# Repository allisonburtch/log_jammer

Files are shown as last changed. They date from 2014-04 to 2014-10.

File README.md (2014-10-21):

Hi there. I found [this](http://www.electroschematics.com/wp-content/uploads/2009/01/cell-phone-jammer-schematic.gif) cell phone jammer on the internet. It is for the GSM 1900 spectrum. Many of these parts are legacy and I had to figure out replacements. If you look at the actual schematic in Eagle, I've noted the new name of each part. Feel free to email me with questions: allison//at//allisonburtch.net

Schematic in Eagle of triangle wave generator, voltage inverter and noise generator.
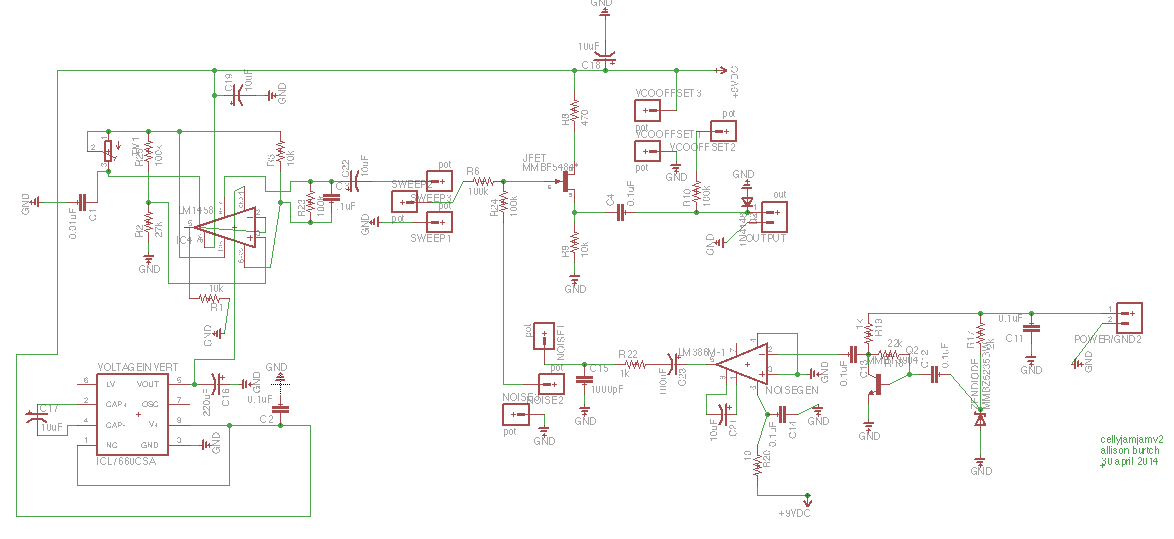
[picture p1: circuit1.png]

Schematic of the VCO and rf amplifier leading to antenna.
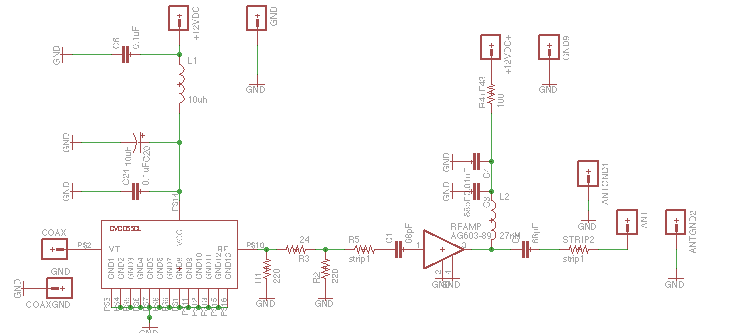
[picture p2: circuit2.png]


This is the board layout of the rf part in Eagle.
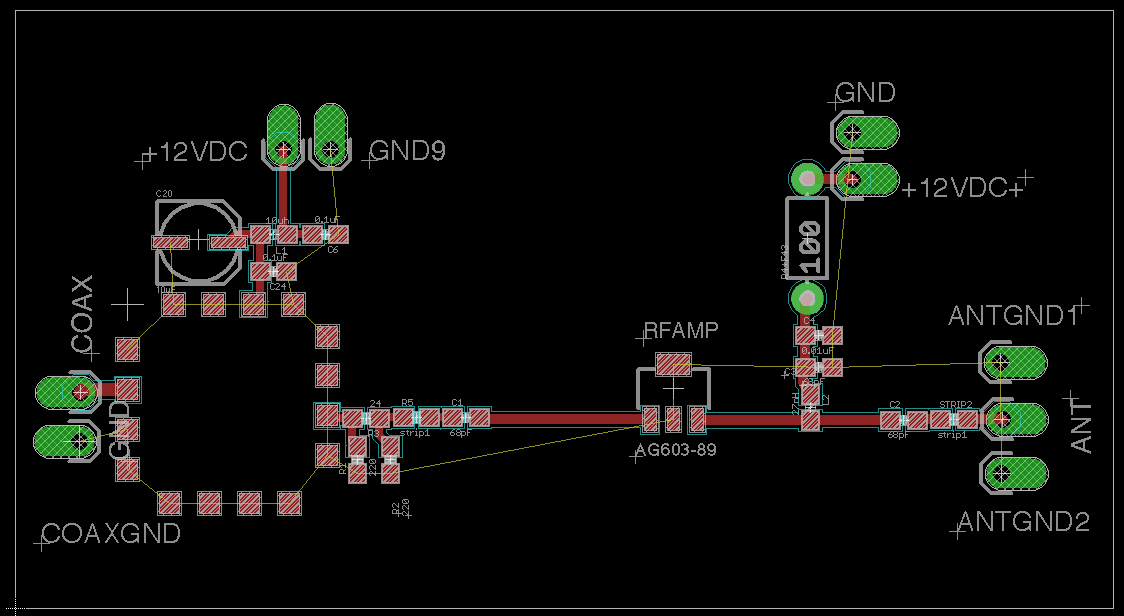
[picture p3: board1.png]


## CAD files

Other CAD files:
jammer_smdv3-tcream.dxf
rf_part/rfv1-tcream.dxf
vinyl_cut_rf_board/rfv1_multiple-tcream.dxf
cellyjamjam_v2-tcream.dxf
rf_part/rfv1-bcream.dxf
vinyl_cut_rf_board/rfv1_multiple-bcream.dxf
jammer_smdv3-bcream.dxf

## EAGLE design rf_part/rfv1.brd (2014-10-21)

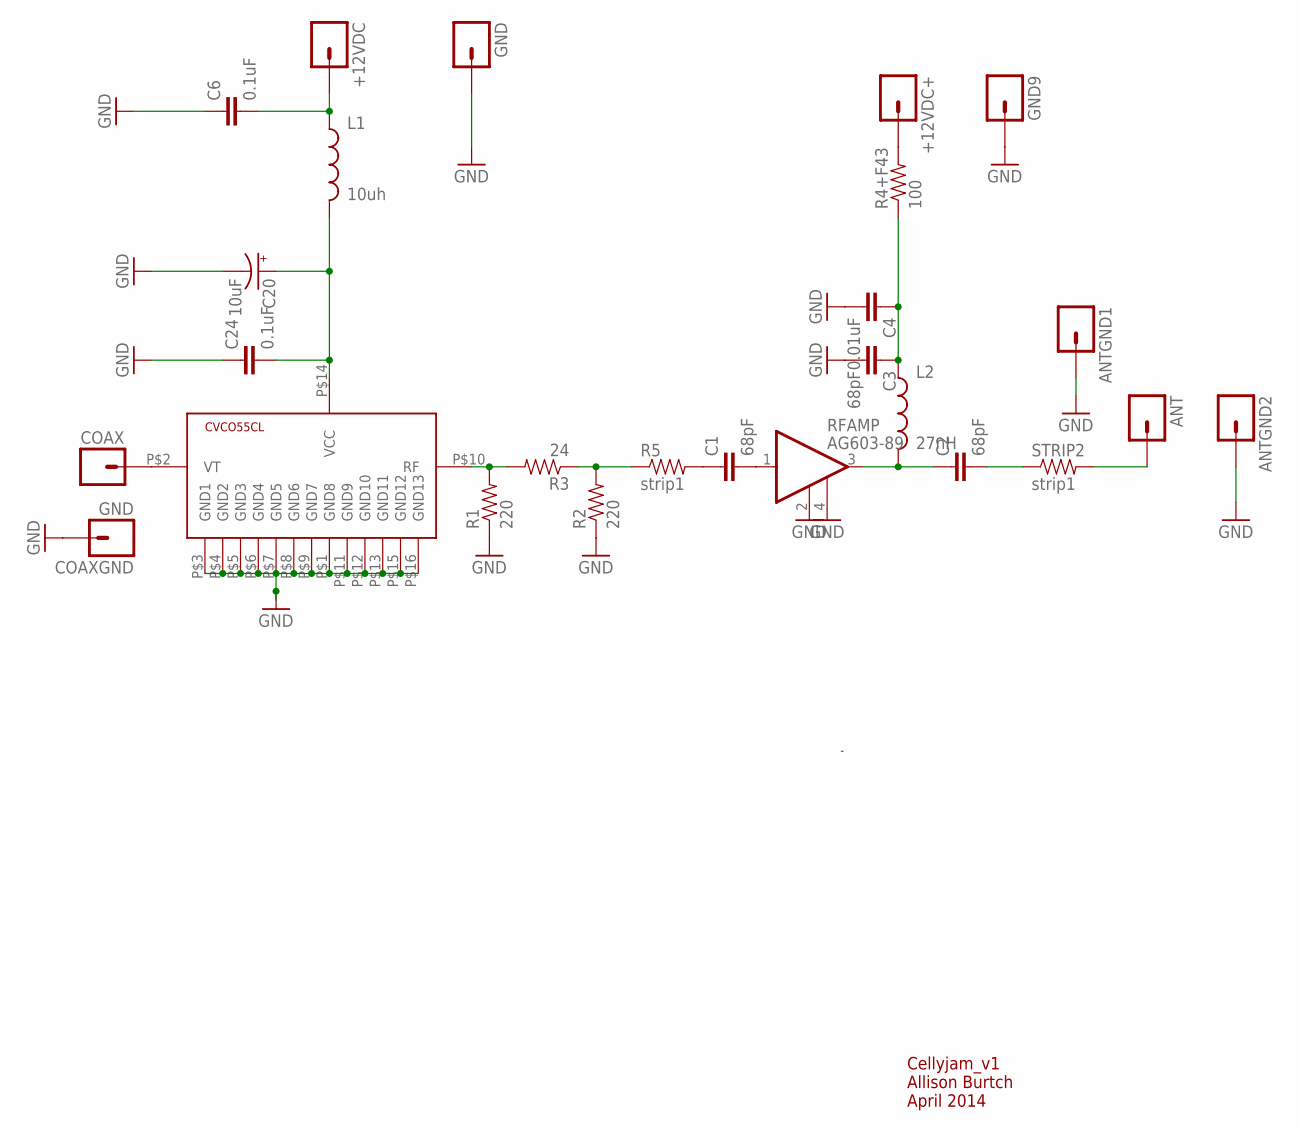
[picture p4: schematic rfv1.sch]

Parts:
+12VDC, +12VDC+: M01OFFSET; 1X01_OFFSET
ANT: M01OFFSET; 1X01_OFFSET
ANTGND1, ANTGND2: M01OFFSET; 1X01_OFFSET
C1, C2, C3: 68pF; 0603-CAP
C4: 0.01uF; 0603-CAP
C6, C24: 0.1uF; 0603-CAP
C20: 10uF; PANASONIC_C
COAX: M01OFFSET; 1X01_OFFSET
COAXGND: GND; 1X01_OFFSET
GND, GND9: M01OFFSET; 1X01_OFFSET
L1: 10uh; 0603
L2: 27nH; 0603
R1, R2: 220; 0603-RES
R3: 24; 0603-RES
R4+F43: 100; AXIAL-0.3-KIT
R5: strip1; 0603-RES
RFAMP: AG603-89; SOT89
STRIP2: strip1; 0603-RES
U$1: CVCO55CL

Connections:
GND: ANTGND1.1, ANTGND2.1, C3.2, C4.2, C6.1, C20.-, C24.1, COAXGND.1, GND.1, GND9.1, R1.1, R2.1, RFAMP.2 (GND), RFAMP.4 (GND), U$1.P$1 (GND8), U$1.P$3 (GND1), U$1.P$4 (GND2), U$1.P$5 (GND3), U$1.P$6 (GND4), U$1.P$7 (GND5), U$1.P$8 (GND6), U$1.P$9 (GND7), U$1.P$11 (GND9), U$1.P$12 (GND10), U$1.P$13 (GND11), U$1.P$15 (GND12), U$1.P$16 (GND13)
unnamed: COAX.1, U$1.P$2 (VT)
unnamed: R1.2, R3.2, U$1.P$10 (RF)
unnamed: R2.2, R3.1, R5.1
unnamed: C1.2, RFAMP.1 (IN)
unnamed: C2.1, L2.2, RFAMP.3 (OUT)
unnamed: C3.1, C4.1, L2.1, R4+F43.P$1 (1)
unnamed: +12VDC.1, C6.2, L1.1
unnamed: +12VDC+.1, R4+F43.P$2 (2)
unnamed: C2.2, STRIP2.1
unnamed: ANT.1, STRIP2.2
unnamed: C1.1, R5.2
unnamed: C20.+, C24.2, L1.2, U$1.P$14 (VCC)

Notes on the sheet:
Cellyjam_v1 Allison Burtch April 2014

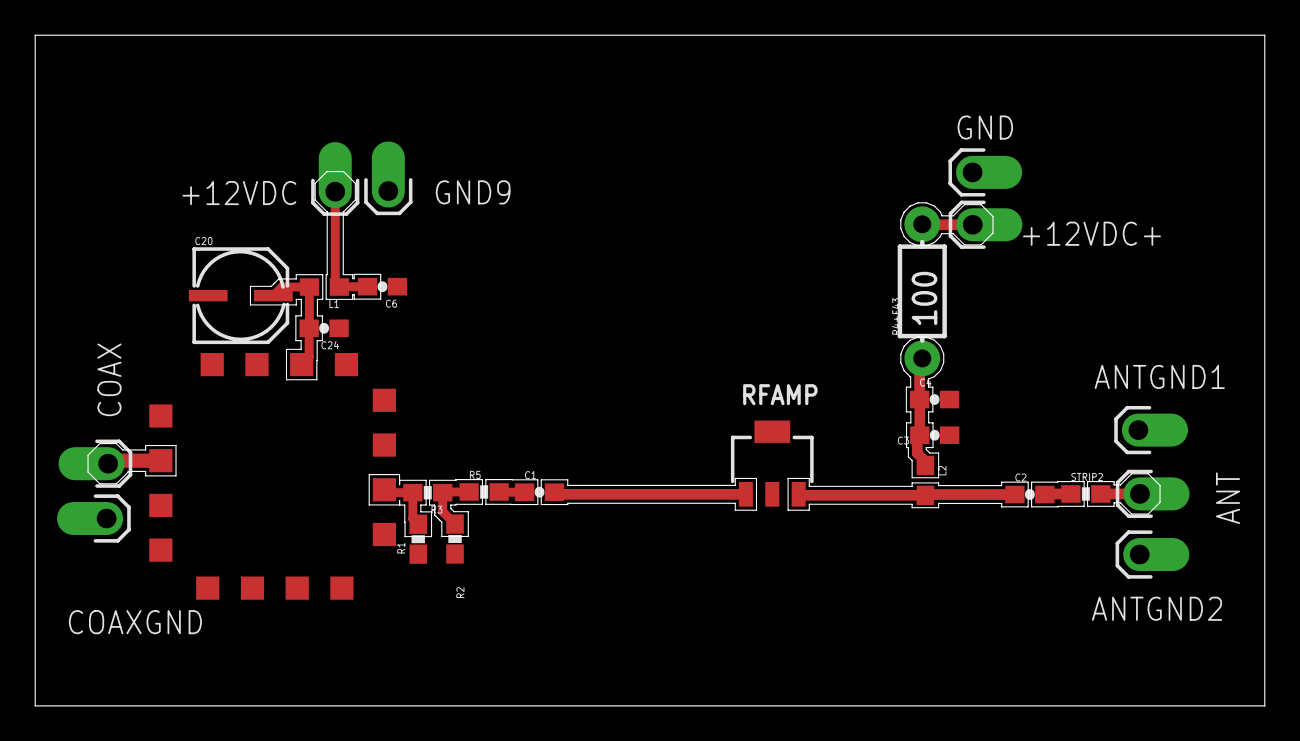
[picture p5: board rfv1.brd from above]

Board: 2 copper layers, 69.8 x 38.1 mm, 26 parts (0 on the bottom side), 13 nets.

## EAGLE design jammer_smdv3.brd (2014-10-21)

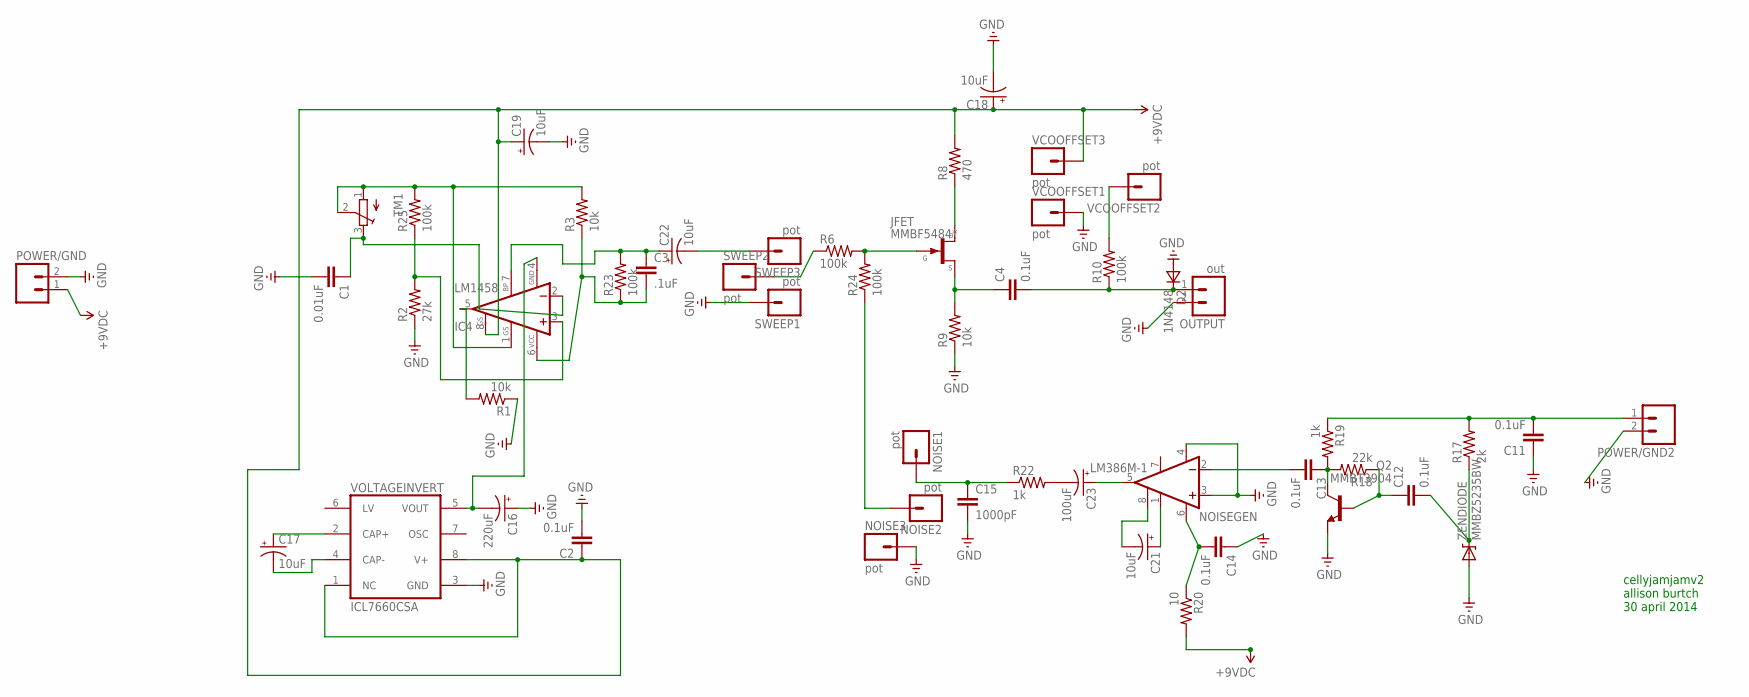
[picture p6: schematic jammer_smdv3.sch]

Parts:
C1: 0.01uF; 0603-CAP
C2, C4, C11, C12, C13, C14: 0.1uF; 0603-CAP
C3: .1uF; 0603-CAP
C15: 1000pF; 0603-CAP
C16: 220uF; PANASONIC_D
C17, C22: 10uF; PANASONIC_C
C18, C19, C21: 10uF; EIA3216
C23: 100uF; CPOL-RADIAL-100UF-25V
D2: 1N4148; SOD323
IC4: LM1458; SO08@2
JFET: MMBF5484*; SOT23
NOISE1, NOISE2, NOISE3: pot; 1X01
NOISEGEN: LM386M-1; SO08
OUTPUT: out; 1X02_LOCK_LONGPADS
POWER/GND, POWER/GND2: M02LOCK_LONGPADS; 1X02_LOCK_LONGPADS
Q2: MMBT3904; SOT23-BEC
R1, R3, R9: 10k; 0603-RES
R2: 27k; 0603-RES
R6, R10, R23, R24, R25: 100k; 0603-RES
R8: 470; 0603-RES
R17: 2k; 0603-RES
R18: 22k; 0603-RES
R19, R22: 1k; 0603-RES
R20: 10; 0603-RES
SWEEP1, SWEEP2, SWEEP3: pot; 1X01
TM1: TRIMPOTTC33X; TC33X
VCOOFFSET1, VCOOFFSET2, VCOOFFSET3: pot; 1X01
VOLTAGEINVERT: ICL7660CSA; SO08
ZENDIODE: MMBZ5235BW; DIODE-ZENER

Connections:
GND: C1.2, C2.2, C11.1, C14.1, C15.2, C16.+, C18.C (-), C19.C (-), D2.2 (A), NOISE3.1, NOISEGEN.3 (+IN), NOISEGEN.4 (GND), OUTPUT.2, POWER/GND.2, POWER/GND2.2, Q2.E, R1.1, R2.1, R9.1, SWEEP1.1, VCOOFFSET1.1, VOLTAGEINVERT.3 (GND), ZENDIODE.P$2 (A)
unnamed: C17.+, VOLTAGEINVERT.2 (CAP+)
unnamed: C17.-, VOLTAGEINVERT.4 (CAP-)
unnamed: C21.A (+), NOISEGEN.1 (GAIN)
unnamed: C16.-, IC4.4 (GND), VOLTAGEINVERT.5 (VOUT)
unnamed: IC4.1 (GAIN), R3.2, R25.2, TM1.1 (A), TM1.2 (S)
unnamed: C1.1, IC4.2 (-IN), TM1.3 (E)
unnamed: R6.1, SWEEP2.1
unnamed: C22.-, SWEEP3.1
unnamed: C3.2, IC4.6 (VS), R3.1, R23.1
unnamed: C21.C (-), NOISEGEN.8 (GAIN)
unnamed: C12.1, Q2.B, R18.1
unnamed: C13.2, NOISEGEN.2 (-IN)
unnamed: C13.1, Q2.C, R18.2, R19.2
unnamed: C12.2, R17.1, ZENDIODE.P$1 (C)
unnamed: C23.2 (-), R22.2
unnamed: C23.1 (+), NOISEGEN.5 (OUT)
unnamed: C15.1, NOISE1.1, R22.1
unnamed: C3.1, C22.+, IC4.7 (BS2), R23.2
unnamed: NOISE2.1, R24.1
unnamed: C14.2, NOISEGEN.6 (VS), R20.1
unnamed: JFET.1 (D), R8.1
unnamed: C4.1, JFET.2 (S), R9.2
unnamed: R10.2, VCOOFFSET2.1
unnamed: C11.2, POWER/GND2.1, R17.2, R19.1
unnamed: JFET.3 (G), R6.2, R24.2
unnamed: IC4.5 (OUT), R1.2
unnamed: IC4.3 (+IN), R2.2, R25.1
unnamed: C4.2, D2.1 (C), OUTPUT.1, R10.1
VCC: C2.1, C18.A (+), C19.A (+), IC4.8 (GAIN), POWER/GND.1, R8.2, R20.2, VCOOFFSET3.1, VOLTAGEINVERT.1 (NC), VOLTAGEINVERT.8 (V+)

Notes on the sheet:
cellyjamjamv2 allison burtch 30 april 2014

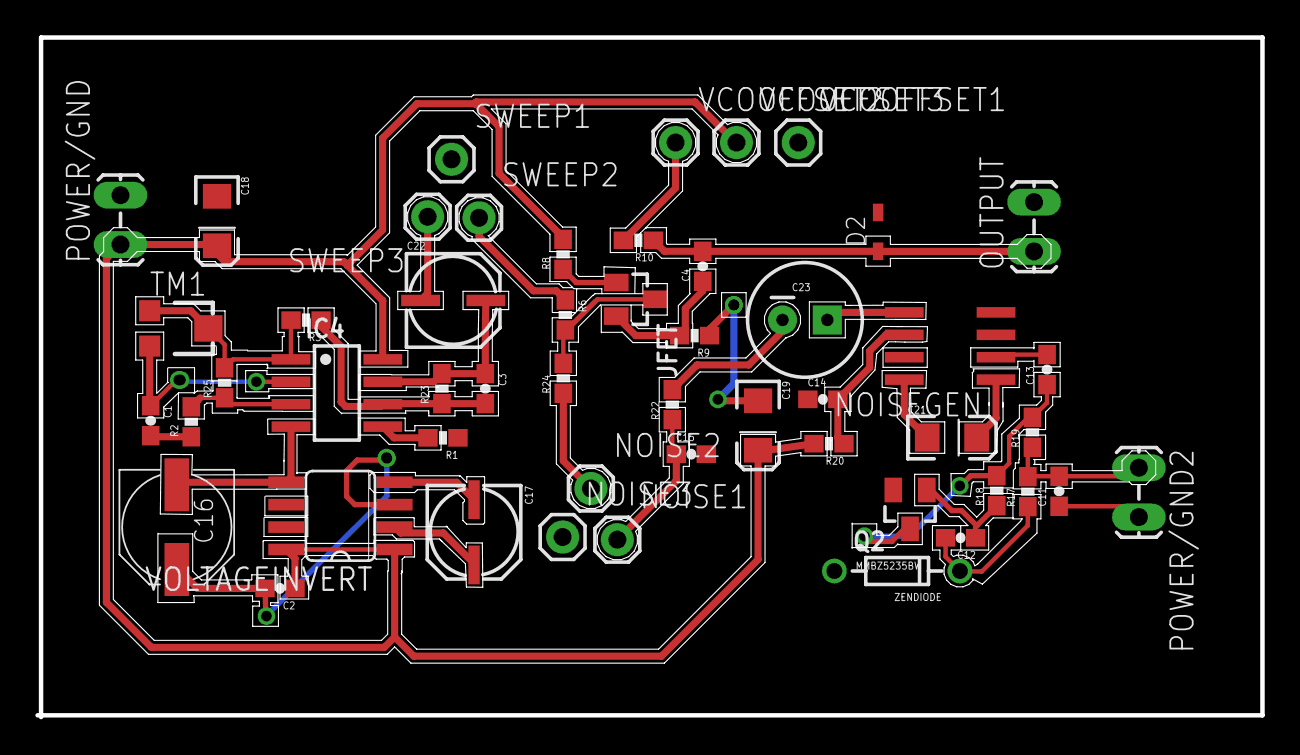
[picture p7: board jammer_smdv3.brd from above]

Board: 2 copper layers, 69.4 x 38.5 mm, 51 parts (0 on the bottom side), 30 nets.

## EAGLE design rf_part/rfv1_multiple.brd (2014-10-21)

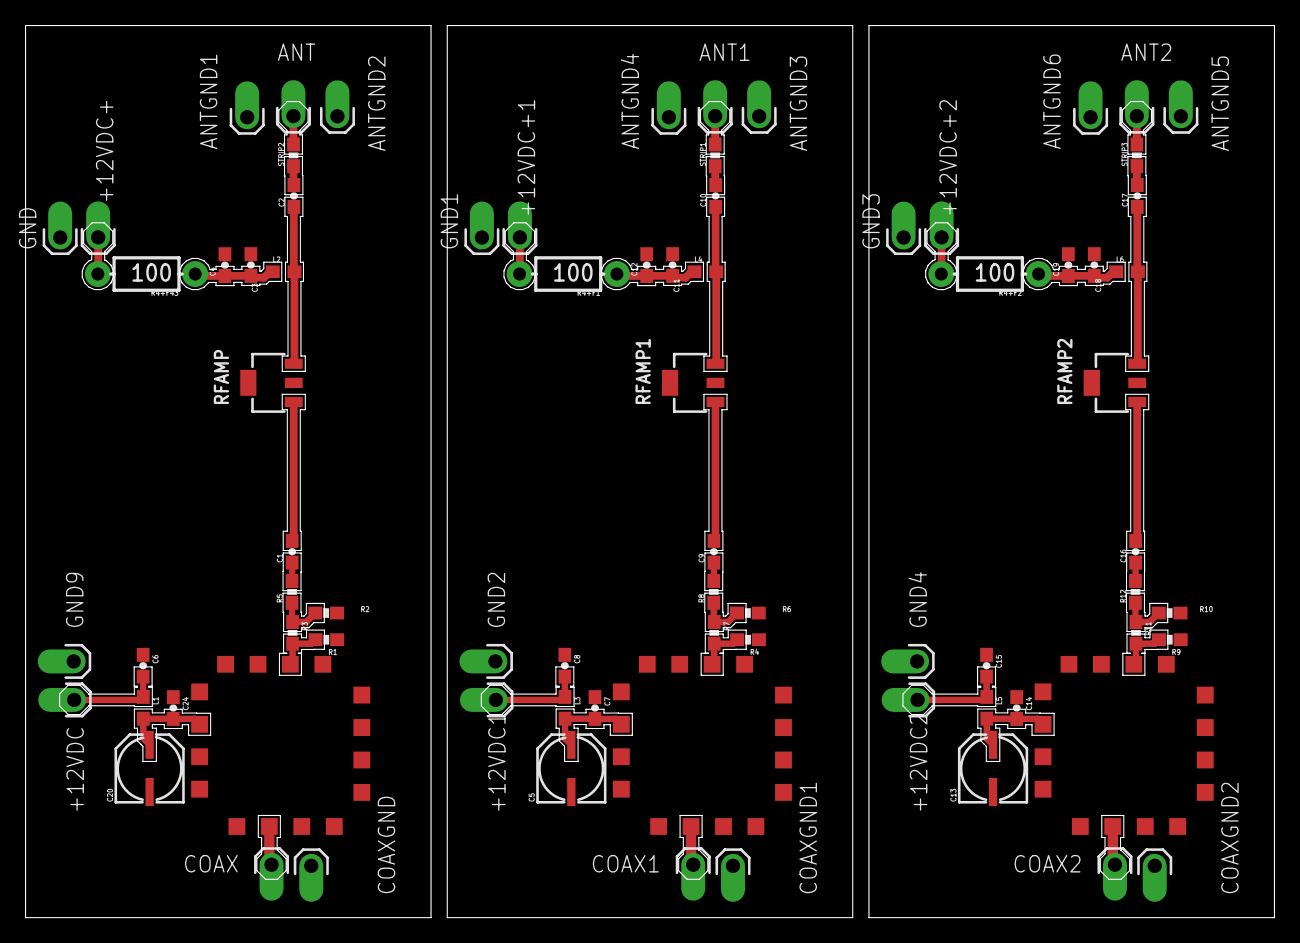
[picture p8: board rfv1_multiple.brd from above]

Board: 2 copper layers, 97.8 x 69.8 mm, 78 parts (0 on the bottom side), 39 nets.

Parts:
+12VDC, +12VDC1, +12VDC2, +12VDC+, +12VDC+1, +12VDC+2: 1X01_OFFSET
ANT, ANT1, ANT2: 1X01_OFFSET
ANTGND1, ANTGND2, ANTGND3, ANTGND4, ANTGND5, ANTGND6: 1X01_OFFSET
C1, C2, C3, C9, C10, C11, C16, C17, C18: 68pF; 0603-CAP
C4, C12, C19: 0.01uF; 0603-CAP
C5, C13, C20: 10uF; PANASONIC_C
C6, C7, C8, C14, C15, C24: 0.1uF; 0603-CAP
COAX, COAX1, COAX2: 1X01_OFFSET
COAXGND, COAXGND1, COAXGND2: GND; 1X01_OFFSET
GND, GND1, GND2, GND3, GND4, GND9: 1X01_OFFSET
L1, L3, L5: 10uh; 0603
L2, L4, L6: 27nH; 0603
R1, R2, R4, R6, R9, R10: 220; 0603-RES
R3, R7, R11: 24; 0603-RES
R4+F1, R4+F2, R4+F43: 100; AXIAL-0.3-KIT
R5, R8, R12: strip1; 0603-RES
RFAMP, RFAMP1, RFAMP2: AG603-89; SOT89
STRIP1, STRIP2, STRIP3: strip1; 0603-RES
U$1, U$2, U$3: CVCO55CL

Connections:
GND: ANTGND1.1, ANTGND2.1, C3.2, C4.2, C6.1, C20.-, C24.1, COAXGND.1, GND.1, GND9.1, R1.1, R2.1, RFAMP.2, RFAMP.4, U$1.P$1, U$1.P$3, U$1.P$4, U$1.P$5, U$1.P$6, U$1.P$7, U$1.P$8, U$1.P$9, U$1.P$11, U$1.P$12, U$1.P$13, U$1.P$15, U$1.P$16
GND1: ANTGND3.1, ANTGND4.1, C5.-, C7.1, C8.1, C11.2, C12.2, COAXGND1.1, GND1.1, GND2.1, R4.1, R6.1, RFAMP1.2, RFAMP1.4, U$2.P$1, U$2.P$3, U$2.P$4, U$2.P$5, U$2.P$6, U$2.P$7, U$2.P$8, U$2.P$9, U$2.P$11, U$2.P$12, U$2.P$13, U$2.P$15, U$2.P$16
GND2: ANTGND5.1, ANTGND6.1, C13.-, C14.1, C15.1, C18.2, C19.2, COAXGND2.1, GND3.1, GND4.1, R9.1, R10.1, RFAMP2.2, RFAMP2.4, U$3.P$1, U$3.P$3, U$3.P$4, U$3.P$5, U$3.P$6, U$3.P$7, U$3.P$8, U$3.P$9, U$3.P$11, U$3.P$12, U$3.P$13, U$3.P$15, U$3.P$16
unnamed: COAX.1, U$1.P$2
unnamed: R1.2, R3.2, U$1.P$10
unnamed: R2.2, R3.1, R5.1
unnamed: C1.2, RFAMP.1
unnamed: C2.1, L2.2, RFAMP.3
unnamed: C3.1, C4.1, L2.1, R4+F43.P$1
unnamed: +12VDC.1, C6.2, L1.1
unnamed: +12VDC+.1, R4+F43.P$2
unnamed: C2.2, STRIP2.1
unnamed: ANT.1, STRIP2.2
unnamed: C1.1, R5.2
unnamed: C5.+, C7.2, L3.2, U$2.P$14
unnamed: COAX1.1, U$2.P$2
unnamed: R4.2, R7.2, U$2.P$10
unnamed: R6.2, R7.1, R8.1
unnamed: C9.2, RFAMP1.1
unnamed: C10.1, L4.2, RFAMP1.3
unnamed: C11.1, C12.1, L4.1, R4+F1.P$1
unnamed: +12VDC1.1, C8.2, L3.1
unnamed: +12VDC+1.1, R4+F1.P$2
unnamed: C10.2, STRIP1.1
unnamed: ANT1.1, STRIP1.2
unnamed: C9.1, R8.2
unnamed: C13.+, C14.2, L5.2, U$3.P$14
unnamed: COAX2.1, U$3.P$2
unnamed: R9.2, R11.2, U$3.P$10
unnamed: R10.2, R11.1, R12.1
unnamed: C16.2, RFAMP2.1
unnamed: C17.1, L6.2, RFAMP2.3
unnamed: C18.1, C19.1, L6.1, R4+F2.P$1
unnamed: +12VDC2.1, C15.2, L5.1
unnamed: +12VDC+2.1, R4+F2.P$2
unnamed: C17.2, STRIP3.1
unnamed: ANT2.1, STRIP3.2
unnamed: C16.1, R12.2
unnamed: C20.+, C24.2, L1.2, U$1.P$14

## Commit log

2014-03-11 finished schematic, now onto board. jeeez
    [celly_jamjam.brd, celly_jamjam.sch]
2014-03-14 design is better
    [celly_jamjam.brd, celly_jamjam.sch]
2014-03-17 added correct VCO
    [celly_jamjam.brd, celly_jamjam.sch]
2014-03-24 added VCO, changed design. still needs a lot of work
    [celly_jamjam.brd]
2014-04-20 changed everything to SMD. much work to be done
    [celly_jamjam.brd, celly_jamjam.sch]
2014-04-30 surface mount board
    [cellyjamjam_v2.brd, cellyjamjam_v2.sch]
2014-05-01 fuuuuuuu had to hand draw the ulp
    [cellyjamjam_v2.brd, cellyjamjam_v2.sch]
2014-05-02 mill file traces were too close. redrew them.
    [cellyjamjam_v2-bcream.dxf, cellyjamjam_v2-tcream.dxf, cellyjamjam_v2.brd]
2014-05-02 changed board
    [cellyjamjam_v2.brd]
2014-05-03 third version of design
    [jammer_smdv3.brd, jammer_smdv3.sch]
2014-10-21 updated github with rf board and vinyl stencil
    [jammer_smdv3-bcream.dxf, jammer_smdv3-tcream.dxf, jammer_smdv3.brd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]

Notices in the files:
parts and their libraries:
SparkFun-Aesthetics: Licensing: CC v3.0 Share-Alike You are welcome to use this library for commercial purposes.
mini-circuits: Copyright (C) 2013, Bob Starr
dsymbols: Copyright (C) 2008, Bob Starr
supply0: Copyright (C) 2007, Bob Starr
